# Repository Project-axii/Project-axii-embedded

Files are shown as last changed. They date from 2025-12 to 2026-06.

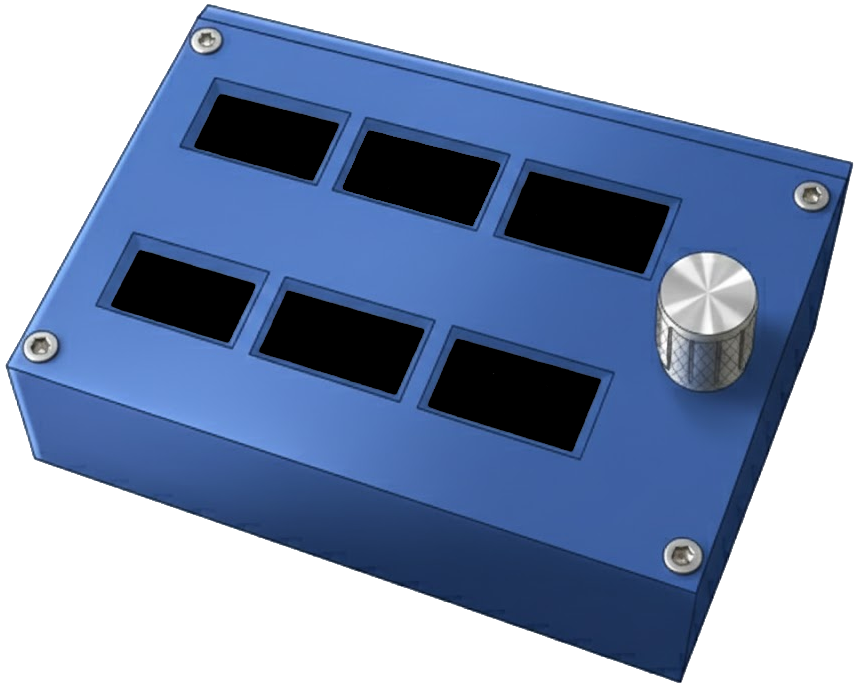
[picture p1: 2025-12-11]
Nexus/nexus.png

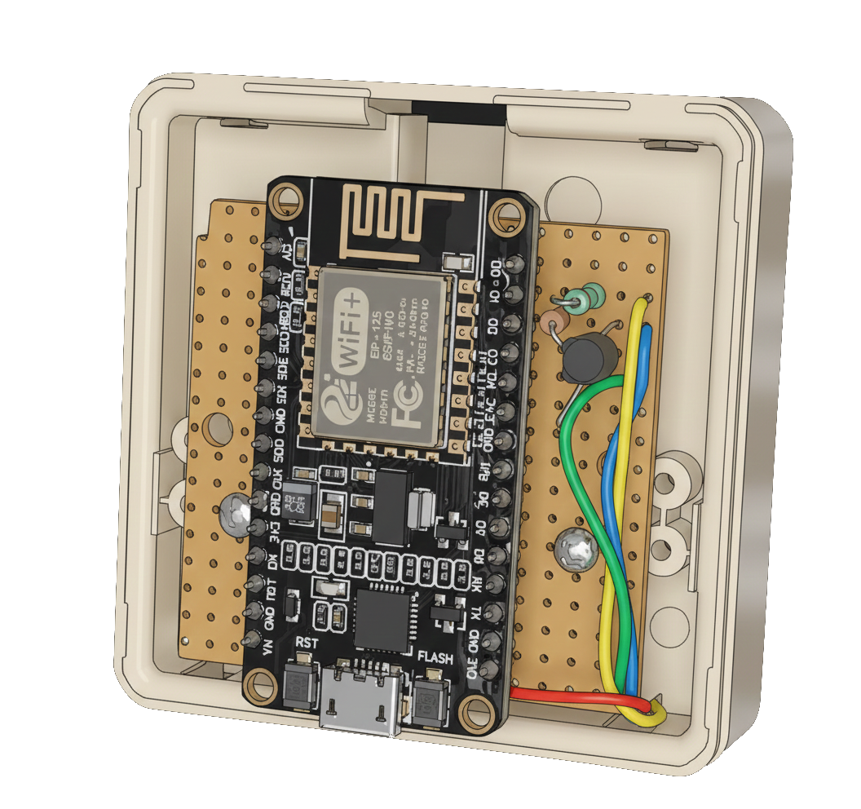
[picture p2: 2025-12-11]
Power Link/Power link.png

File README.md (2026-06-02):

<div align="center">

AXII Logo

# AXII — Embedded (Firmware IoT)

**Firmware dos dispositivos físicos do sistema AXII para automação de salas de aula, desenvolvido com ESP8266 e programado em C++ via Arduino IDE.**







</div>

---

## Sobre o Projeto

O **AXII Embedded** contém o firmware de três módulos físicos baseados em **ESP8266 (WeMos D1 Mini)** que integram o sistema AXII à infraestrutura real da sala de aula. Esses módulos se comunicam com a mesma API PHP compartilhada com o painel web e o app mobile, executando ações físicas com base no estado dos dispositivos registrados no banco de dados.

O sistema AXII completo é composto por:
- **Embedded** (este repositório) — módulos físicos IoT que atuam diretamente nos equipamentos
- **Web** — painel de controle via navegador
- **Mobile** — controle e monitoramento pelo celular
- **Desktop** — cliente instalado nos computadores das salas

---

## Módulos

### AX-LM — Controlador de Iluminação
Controla a **iluminação da sala** por meio de um relé conectado ao ESP8266. Consulta a API a cada 5 segundos e liga ou desliga a luz conforme o status do dispositivo.

### Power Link — Controle de Energia dos PCs
Simula o pressionamento do **botão físico de power** dos computadores. Detecta mudanças de estado na API e envia um pulso elétrico de 500ms ao botão de energia do PC.

### Nexus — Central de Controle Manual
Painel físico com **4 botões** que permite ao professor controlar todos os dispositivos da sala sem precisar do celular ou computador. Cada botão alterna o estado de um dispositivo na API.

---

## Como funciona

```
┌───────────────────────────────────────────┐
│              API AXII (PHP)               │
│         Banco de dados de dispositivos    │
└──────────────┬────────────────────────────┘
               │  HTTP (GET/POST)
    ┌──────────┼─────────────────────┐
    ↓           ↓                    ↓
┌─────────┐  ┌────────────┐   ┌──────────┐
│  AX-LM  │  │ Power Link │   │  Nexus   │
│ (Relé)  │  │ (Pulso D2) │   │(4 Botões)│
│ ID: 7   │  │  ID: 6     │   │IDs:4,5,6,7│
└─────────┘  └────────────┘   └──────────┘
 Iluminação   Liga/desliga PC   Controle manual
```

**Fluxo de controle:**
- **AX-LM e Power Link** — controladores automáticos: consultam a API periodicamente e executam ações físicas com base no status retornado.
- **Nexus** — controlador manual: o botão pressiona → atualiza o status na API → os outros módulos respondem automaticamente à mudança.

---

## Módulos em Detalhe

### AX-LM — Controlador de Iluminação

| Propriedade | Valor |
|---|---|
| Arquivo | `AX-LM/wemos_lamp.ino` |
| ID do Dispositivo | `7` |
| Pino GPIO | `D2` (relé) |
| AP de Configuração | `AX-LM_CONFIG` / senha: `12345678` |
| OTA Hostname | `AX-LM` |
| OTA Senha | `admin123` |
| Intervalo de Consulta | 5 segundos |

**Lógica de operação:**
- Consulta a API a cada 5 segundos com `GET {apiBaseUrl}?id=7`
- Se `ativo = true` e `status = "offline"` → **liga o relé** (iluminação acesa)
- Se `ativo = false` ou `status = "online"` → **desliga o relé** (iluminação apagada)
- Atualiza o campo `ultima_conexao` na API ao ligar o relé

**Arquivos de hardware:**
- `circuito.pdf` — diagrama do circuito elétrico

---

### Power Link — Controle de Energia dos PCs

| Propriedade | Valor |
|---|---|
| Arquivo | `Power Link/wemos_pc.ino` |
| ID do Dispositivo | `6` |
| Pino GPIO | `D2` (pulso no botão de power) |
| AP de Configuração | `AXII_POWERLINK` / senha: `12345678` |
| OTA Hostname | `AXII Power Link` |
| OTA Senha | `admin123` |
| Duração do Pulso | 500ms |
| Intervalo de Consulta | 5 segundos |

**Lógica de operação:**
- Consulta a API a cada 5 segundos com `GET {apiBaseUrl}?id=6`
- Armazena o estado inicial na primeira leitura
- Quando detecta uma **mudança de estado** (`online → offline` ou `offline → online`) → envia um pulso de 500ms no pino D2
- O pulso simula o pressionamento físico do botão de power do PC
- Atualiza `ultima_conexao` na API após cada acionamento

**Arquivos de hardware:**
- `circuito.png` — diagrama do circuito
- `Power link.png` — foto/referência visual do módulo

---

### Nexus — Central de Controle Manual

| Propriedade | Valor |
|---|---|
| Arquivo | `Nexus/wemos-nexus.ino` |
| Pinos GPIO | `D5`, `D6`, `D7`, `D8` (botões) |
| AP de Configuração | `NEXUS_CONFIG` / senha: `12345678` |
| OTA Hostname | `ESP8266-NEXUS` |
| OTA Senha | `admin` |
| Debounce | 200ms |

**Mapeamento de botões:**

| Botão | Pino | ID Dispositivo | Equipamento |
|---|---|---|---|
| Botão 1 | `D5` | 7 | PC / Lab |
| Botão 2 | `D6` | 6 | Ar-condicionado |
| Botão 3 | `D7` | 4 | Projetor |
| Botão 4 | `D8` | 5 | Iluminação |

**Lógica de operação:**
- Ao pressionar um botão, consulta o status atual do dispositivo na API
- Alterna o status: `online → offline` ou `offline → online`
- Envia o novo status via `POST` à API
- LED embutido pisca ao pressionar um botão
- **Reset manual:** segure o botão D5 por 3 segundos para apagar as credenciais WiFi salvas

**Arquivos de hardware:**
- `circuit.pdf` — diagrama do circuito elétrico
- `nexus.png` — foto/referência visual do módulo
- `model 3d/AXII Nexus.stl` — modelo 3D para impressão da carcaça
- `model 3d/AXII Nexus.glb` — modelo 3D em formato GLB (visualização)

---

## Funcionalidades Comuns

Todos os três módulos compartilham as seguintes funcionalidades:

| Funcionalidade | Descrição |
|---|---|
| **Portal de Configuração WiFi** | Ao ligar sem credenciais salvas, cria um ponto de acesso WiFi próprio. O usuário conecta e acessa `http://192.168.4.1` para configurar a rede via navegador |
| **Persistência em EEPROM** | As credenciais WiFi são salvas na memória interna do ESP8266 e sobrevivem a reinicializações |
| **Reconexão automática** | Se o WiFi cair, tenta reconectar automaticamente. Após 5 falhas consecutivas, entra novamente em modo de configuração |
| **OTA (Over-the-Air)** | Atualização de firmware via rede WiFi sem precisar conectar o cabo USB |
| **Monitor Serial** | Logs detalhados via porta serial a 115200 baud para depuração |
| **Limpeza de configuração** | Interface web com botão para apagar credenciais e retornar ao modo de configuração |

---

## Integração com a API

Todos os módulos se comunicam com a API via HTTP. A URL base deve ser configurada na constante `apiBaseUrl` em cada arquivo `.ino`.

### Endpoints utilizados

| Método | Chamada | Descrição |
|---|---|---|
| `GET` | `{apiBaseUrl}?id={idDispositivo}` | Consulta o status atual do dispositivo |
| `GET` | `{apiBaseUrl}?action=update&id={idDispositivo}` | Atualiza o campo `ultima_conexao` |
| `POST` | `{apiBaseUrl}` com body JSON | Alterna o status do dispositivo (Nexus) |

### Formatos de resposta suportados

Os módulos aceitam dois formatos de resposta da API:

```json
// Formato 1
{
  "success": true,
  "data": {
    "id": 7,
    "nome": "Iluminação Sala A",
    "status": "online",
    "ativo": true
  }
}

// Formato 2 (resposta direta)
{
  "id": 7,
  "nome": "Iluminação Sala A",
  "status": "online",
  "ativo": true
}
```

### Payload de atualização de status (Nexus)

```json
POST {apiBaseUrl}
Content-Type: application/json

{
  "id": 7,
  "status": "offline"
}
```

---

## Requisitos de Hardware

### Componentes comuns (todos os módulos)
- **Microcontrolador:** ESP8266 — WeMos D1 Mini (ou equivalente)
- **Alimentação:** 5V via USB
- **Rede WiFi:** 2,4 GHz (o ESP8266 não suporta 5 GHz)

### Componentes por módulo

| Módulo | Hardware adicional |
|---|---|
| **AX-LM** | 1× módulo relé (5V), fiação, luminária |
| **Power Link** | Fios de conexão ao botão de power do PC; optoacoplador ou relé recomendado para isolação elétrica |
| **Nexus** | 4× push buttons, LED embutido no ESP8266, carcaça impressa em 3D (opcional — arquivo STL incluso) |

---

## Bibliotecas Arduino Necessárias

| Biblioteca | Origem | Uso |
|---|---|---|
| `ESP8266WiFi` | ESP8266 Core | Conexão WiFi |
| `ESP8266WebServer` | ESP8266 Core | Portal de configuração captive |
| `ESP8266HTTPClient` | ESP8266 Core | Requisições HTTP à API |
| `ArduinoJson` | Benoit Blanchon (v6.x) | Parsing das respostas JSON da API |
| `ArduinoOTA` | ESP8266 Core | Atualização de firmware via rede |
| `EEPROM` | ESP8266 Core | Persistência das credenciais WiFi |

---

## Como Programar

### 1. Instalar o Arduino IDE

Baixe o [Arduino IDE](https://www.arduino.cc/en/software) (versão 1.8.x ou 2.x).

### 2. Adicionar suporte ao ESP8266

1. Abra o Arduino IDE → **Arquivo** → **Preferências**
2. Em "URLs adicionais para gerenciadores de placas", adicione:
   ```
   http://arduino.esp8266.com/stable/package_esp8266com_index.json
   ```
3. Vá em **Ferramentas** → **Placa** → **Gerenciador de Placas**
4. Pesquise `esp8266` e instale

### 3. Instalar bibliotecas

1. Vá em **Sketch** → **Incluir Biblioteca** → **Gerenciar Bibliotecas**
2. Pesquise e instale: **ArduinoJson** (versão 6.x, autor: Benoit Blanchon)
3. As demais bibliotecas vêm com o ESP8266 Core

### 4. Configurar o firmware

Abra o arquivo `.ino` do módulo desejado e configure:

```cpp
// URL da API (substitua pelo endereço real)
const char* apiBaseUrl = "http://seu-servidor.com/tcc-axii/Project-Axii-api/api/devices/list.php";

// ID do dispositivo no banco de dados (verifique na API)
const int idDispositivo = 7;
```

> As credenciais WiFi **não precisam** ser inseridas no código — elas são configuradas pelo portal web após a primeira inicialização.

### 5. Fazer upload

1. Conecte o ESP8266 via USB ao computador
2. Selecione a placa: **Ferramentas** → **Placa** → **ESP8266 Boards** → **WeMos D1 R1**
3. Selecione a porta COM correta em **Ferramentas** → **Porta**
4. Clique em **Upload** (→) e aguarde a compilação e gravação

---

## Configuração WiFi no Dispositivo

Após o upload, na primeira inicialização (ou após limpar as credenciais):

1. O módulo cria uma rede WiFi própria (ex: `AX-LM_CONFIG`)
2. Conecte seu celular ou computador a essa rede (senha: `12345678`)
3. Acesse `http://192.168.4.1` no navegador
4. Preencha o SSID e a senha da sua rede WiFi da escola
5. Clique em **Conectar à Rede** — o dispositivo reinicia e entra em operação normal

---

## Atualização OTA (Over-the-Air)

Após a configuração inicial, os módulos podem ser atualizados sem cabo USB:

1. Certifique-se de que o dispositivo está ligado e na mesma rede
2. No Arduino IDE, vá em **Ferramentas** → **Porta** e selecione o dispositivo na rede
3. Digite a senha OTA quando solicitado
4. Faça o upload normalmente

**Senhas e hostnames OTA:**

| Módulo | Hostname OTA | Senha OTA |
|---|---|---|
| AX-LM | `AX-LM` | `admin123` |
| Power Link | `AXII Power Link` | `admin123` |
| Nexus | `ESP8266-NEXUS` | `admin` |

---

## Estrutura do Repositório

```
Project-axii-embedded/
├── AX-LM/
│   ├── wemos_lamp.ino        # Firmware do controlador de iluminação
│   └── circuito.pdf          # Diagrama do circuito elétrico
│
├── Power Link/
│   ├── wemos_pc.ino          # Firmware do controlador de energia dos PCs
│   ├── circuito.png          # Diagrama do circuito
│   └── Power link.png        # Referência visual do módulo
│
├── Nexus/
│   ├── wemos-nexus.ino       # Firmware da central de controle manual
│   ├── circuit.pdf           # Diagrama do circuito elétrico
│   ├── nexus.png             # Foto/referência visual do módulo
│   └── model 3d/
│       ├── AXII Nexus.stl    # Modelo 3D para impressão da carcaça
│       ├── AXII Nexus.glb    # Modelo 3D para visualização
│       └── AXII Nexus.zip    # Arquivos do modelo compactados
│
└── LICENSE
```

---

## Depuração (Serial Monitor)

Conecte o cabo USB e abra o Monitor Serial do Arduino IDE em **115200 baud** para ver os logs em tempo real:

```
========================================
    AXII - Controle de AX-LM
   com Configuração WiFi Integrada
========================================

Credenciais encontradas:
SSID: MinhaRedeEscola
Conectando em: MinhaRedaEscola
...............
 WiFi conectado!
IP: 192.168.1.105
Sistema pronto para uso!

--- Consultando Dispositivo ---
URL: http://servidor.com/api/devices/list.php?id=7
Código HTTP: 200
Status: offline | Ativo: SIM
>>> RELÉ LIGADO - AX-LM ACESA <<<
```

---

## Avisos de Segurança

> **Atenção:** O módulo **AX-LM** pode estar conectado à rede elétrica (iluminação de 127V/220V). Sempre utilize um relé adequado com isolação elétrica e, se necessário, consulte um eletricista. Nunca manipule fiação elétrica com o circuito energizado.

> O módulo **Power Link** é conectado ao botão de power do PC. Recomenda-se o uso de um optoacoplador para isolar eletricamente o ESP8266 do computador.

> Altere as senhas OTA padrão (`admin123` / `admin`) antes de usar em ambiente de produção.

---

## 📄 Licença

Este projeto está licenciado sob a [Licença MIT](LICENSE).

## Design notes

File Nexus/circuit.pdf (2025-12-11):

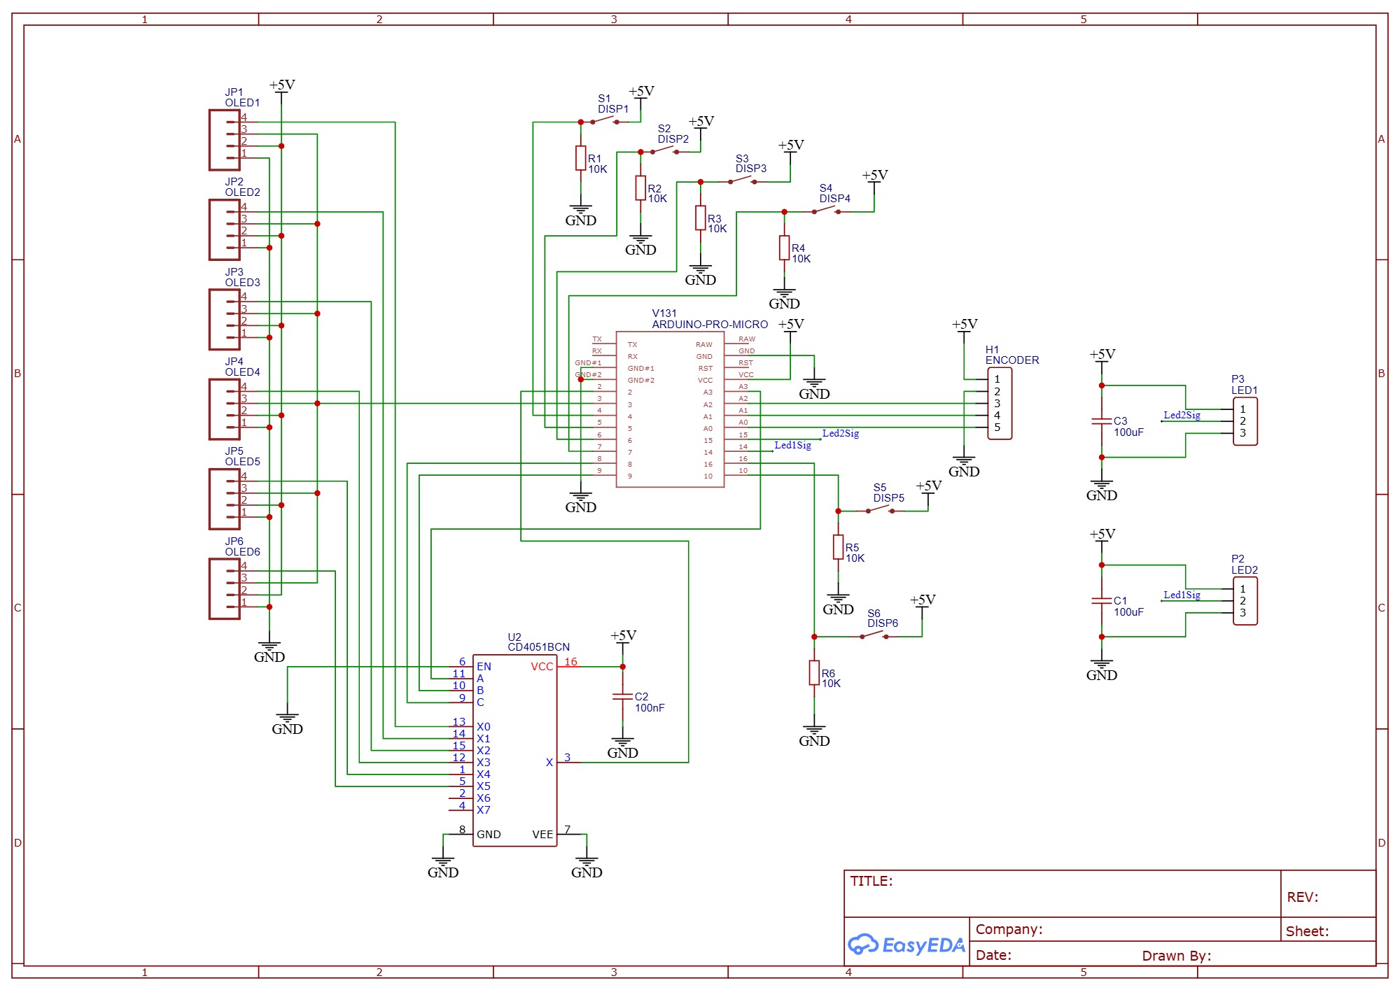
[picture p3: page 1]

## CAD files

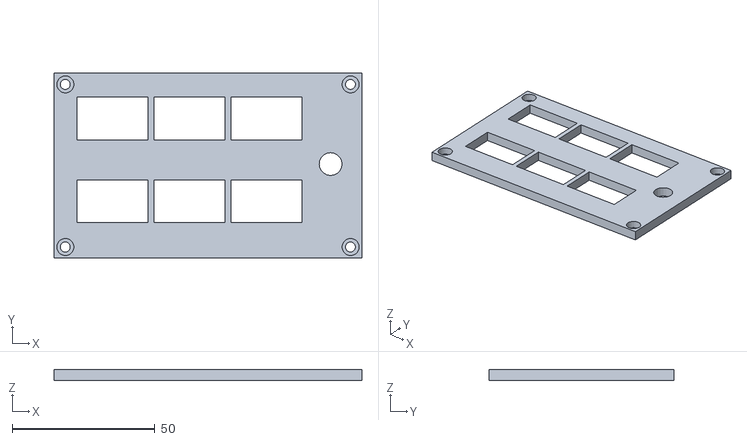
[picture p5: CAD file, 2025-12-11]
Nexus/model 3d/AXII Nexus.stl
108.0 x 65.0 x 4.00

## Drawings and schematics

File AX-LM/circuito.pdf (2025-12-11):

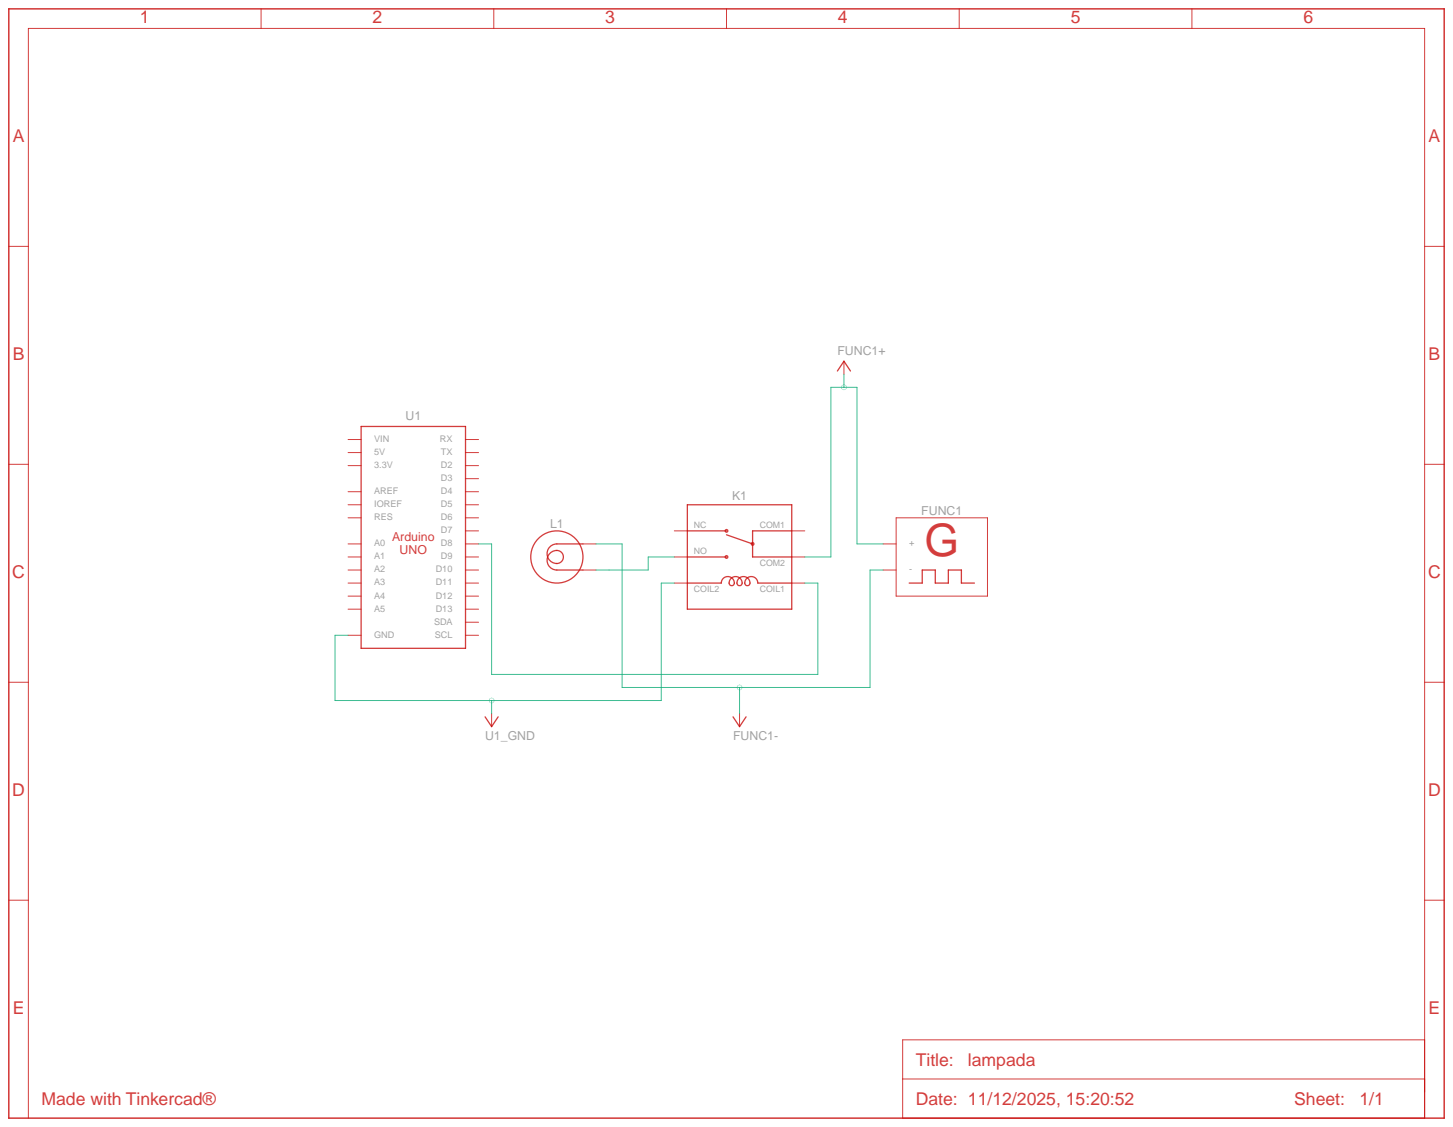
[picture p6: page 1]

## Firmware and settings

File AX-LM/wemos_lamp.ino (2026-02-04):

#include <ESP8266WiFi.h>
#include <ESP8266WebServer.h>
#include <ESP8266HTTPClient.h>
#include <ArduinoJson.h>
#include <ArduinoOTA.h>
#include <EEPROM.h>

// ==================== CONFIGURAÇÕES ====================
const char* apSSID = "AX-LM_CONFIG";        
const char* apPassword = "12345678";        
const char* apiBaseUrl = "LINK_API_DISPOSITIVOS";

const int idDispositivo = 7;

const int pinoRele = D2;

// ==================== VARIÁVEIS GLOBAIS ====================
ESP8266WebServer server(80);
String ssid = "";
String password = "";
bool modoConfiguracao = false;
int falhasConexao = 0;

unsigned long ultimaConsulta = 0;
const unsigned long intervaloConsulta = 5000; 
bool releAtivo = false;

const int LED_BUILTIN_PIN = LED_BUILTIN;

// ==================== FUNÇÕES DE EEPROM ====================
void salvarWiFi(String s, String p) {
  EEPROM.begin(512);
  
  for (int i = 0; i < 200; i++) {
    EEPROM.write(i, 0);
  }
  
  for (int i = 0; i < s.length() && i < 99; i++) {
    EEPROM.write(i, s[i]);
  }
  
  EEPROM.write(100, '|');
  
  for (int i = 0; i < p.length() && i < 99; i++) {
    EEPROM.write(101 + i, p[i]);
  }
  
  EEPROM.commit();
  EEPROM.end();
  
  Serial.println("=== Salvando na EEPROM ===");
  Serial.println("SSID: " + s);
  Serial.print("Senha: ");
  for(int i = 0; i < p.length(); i++) {
    Serial.print("*");
  }
  Serial.println("\n========================");
}

void lerWiFi() {
  EEPROM.begin(512);
  ssid = "";
  password = "";
  
  for (int i = 0; i < 100; i++) {
    char c = EEPROM.read(i);
    if (c == 0 || c == '|') break;
    ssid += c;
  }
  
  for (int i = 101; i < 200; i++) {
    char c = EEPROM.read(i);
    if (c == 0) break;
    password += c;
  }
  
  EEPROM.end();
  
  if (ssid.length() > 0) {
    Serial.println("Credenciais encontradas:");
    Serial.println("SSID: " + ssid);
    Serial.print("Senha: ");
    for(int i = 0; i < password.length(); i++) {
      Serial.print("*");
    }
    Serial.println();
  } else {
    Serial.println("Nenhuma credencial salva");
  }
}

void limparWiFi() {
  EEPROM.begin(512);
  for (int i = 0; i < 200; i++) {
    EEPROM.write(i, 0);
  }
  EEPROM.commit();
  EEPROM.end();
  Serial.println("Credenciais apagadas!");
}

// ==================== SERVIDOR WEB ====================
void handleRoot() {
  String page = R"rawliteral(
  <!DOCTYPE html>
  <html lang="pt-BR">
  <head>
    <meta charset="UTF-8">
    <meta name="viewport" content="width=device-width, initial-scale=1.0">
    <title>AX-LM - Configuração WiFi</title>
    <style>
      * { 
        margin: 0; 
        padding: 0; 
        box-sizing: border-box; 
      }
      
      body {
        font-family: -apple-system, BlinkMacSystemFont, 'Segoe UI', Arial, sans-serif;
        background: linear-gradient(135deg, #1e3c72 0%, #2a5298 50%, #7e22ce 100%);
        min-height: 100vh;
        display: flex;
        flex-direction: column;
        padding: 20px;
        color: #ffffff;
      }
      
      .header {
        display: flex;
        align-items: center;
        justify-content: space-between;
        padding: 20px 0;
        margin-bottom: 30px;
      }
      
      .logo {
        display: flex;
        align-items: center;
        gap: 10px;
      }
      
      .logo-icon {
        width: 40px;
        height: 40px;
        background: #ffc107;
        border-radius: 8px;
        display: flex;
        align-items: center;
        justify-content: center;
        font-weight: bold;
        font-size: 20px;
      }
      
      .logo-text {
        font-size: 28px;
        font-weight: bold;
        letter-spacing: 2px;
      }
      
      .subtitle {
        font-size: 14px;
        color: rgba(255, 255, 255, 0.7);
        font-weight: normal;
        letter-spacing: 1px;
      }
      
      .status-badge {
        background: rgba(255, 193, 7, 0.2);
        padding: 8px 16px;
        border-radius: 20px;
        font-size: 12px;
        backdrop-filter: blur(10px);
        border: 1px solid rgba(255, 193, 7, 0.3);
      }
      
      .container {
        max-width: 500px;
        width: 100%;
        margin: 0 auto;
      }
      
      .card {
        background: rgba(30, 41, 59, 0.7);
        border-radius: 16px;
        padding: 32px;
        backdrop-filter: blur(20px);
        border: 1px solid rgba(255, 255, 255, 0.1);
        box-shadow: 0 20px 60px rgba(0, 0, 0, 0.3);
        margin-bottom: 20px;
      }
      
      .card-title {
        font-size: 22px;
        font-weight: 600;
        margin-bottom: 24px;
        color: #ffffff;
      }
      
      .info-box {
        background: rgba(255, 193, 7, 0.15);
        border-left: 3px solid #ffc107;
        padding: 16px;
        border-radius: 8px;
        margin-bottom: 24px;
      }
      
      .info-box p {
        font-size: 13px;
        line-height: 1.6;
        color: rgba(255, 255, 255, 0.9);
        margin-bottom: 8px;
      }
      
      .info-box p:last-child {
        margin-bottom: 0;
      }
      
      .form-group {
        margin-bottom: 20px;
      }
      
      label {
        display: block;
        font-size: 14px;
        font-weight: 500;
        margin-bottom: 8px;
        color: rgba(255, 255, 255, 0.9);
      }
      
      input[type="text"], 
      input[type="password"] {
        width: 100%;
        padding: 14px;
        background: rgba(255, 255, 255, 0.1);
        border: 1px solid rgba(255, 255, 255, 0.2);
        border-radius: 8px;
        font-size: 15px;
        color: #ffffff;
        transition: all 0.3s;
      }
      
      input[type="text"]::placeholder,
      input[type="password"]::placeholder {
        color: rgba(255, 255, 255, 0.5);
      }
      
      input[type="text"]:focus, 
      input[type="password"]:focus {
        outline: none;
        background: rgba(255, 255, 255, 0.15);
        border-color: #ffc107;
        box-shadow: 0 0 0 3px rgba(255, 193, 7, 0.2);
      }
      
      .btn {
        width: 100%;
        padding: 14px;
        background: #ffc107;
        color: #1e3c72;
        border: none;
        border-radius: 8px;
        font-size: 15px;
        font-weight: 600;
        cursor: pointer;
        transition: all 0.3s;
        margin-top: 12px;
        box-shadow: 0 4px 12px rgba(255, 193, 7, 0.3);
      }
      
      .btn:hover {
        background: #ffb300;
        transform: translateY(-2px);
        box-shadow: 0 6px 20px rgba(255, 193, 7, 0.4);
      }
      
      .btn:active {
        transform: translateY(0);
      }
      
      .btn-reset {
        background: rgba(239, 68, 68, 0.8);
        color: white;
        box-shadow: 0 4px 12px rgba(239, 68, 68, 0.3);
      }
      
      .btn-reset:hover {
        background: rgba(220, 38, 38, 0.9);
        box-shadow: 0 6px 20px rgba(239, 68, 68, 0.4);
      }
      
      .footer {
        text-align: center;
        margin-top: 20px;
        font-size: 13px;
        color: rgba(255, 255, 255, 0.6);
      }
      
      .lamp-icon {
        display: inline-block;
        width: 20px;
        height: 20px;
        background: linear-gradient(135deg, #ffc107 0%, #ff9800 100%);
        border-radius: 50%;
        margin-right: 8px;
        vertical-align: middle;
        box-shadow: 0 0 10px rgba(255, 193, 7, 0.5);
      }
    </style>
  </head>
  <body>
    <div class="header">
      <div class="logo">
        <div class="logo-icon">A</div>
        <div>
          <div class="logo-text">AXII</div>
          <div class="subtitle">AX-LM</div>
        </div>
      </div>
      <div class="status-badge">Modo Configuração</div>
    </div>
    
    <div class="container">
      <div class="card">
        <h2 class="card-title">
          <span class="lamp-icon"></span>
          Configuração de Rede WiFi
        </h2>
        
        <div class="info-box">
          <p><strong>Instruções de Conexão:</strong></p>
          <p>1. Digite o nome da sua rede WiFi (SSID)</p>
          <p>2. Digite a senha da rede</p>
          <p>3. Clique em "Conectar à Rede"</p>
          <p>4. O dispositivo irá reiniciar e controlar a AX-LM automaticamente</p>
        </div>
        
        <form action="/save" method="GET">
          <div class="form-group">
            <label for="ssid">Nome da Rede (SSID)</label>
            <input type="text" id="ssid" name="ssid" placeholder="Digite o nome da sua rede" required>
          </div>
          
          <div class="form-group">
            <label for="pass">Senha da Rede</label>
            <input type="password" id="pass" name="pass" placeholder="Digite a senha">
          </div>
          
          <button type="submit" class="btn">Conectar à Rede</button>
        </form>
      </div>
      
      <div class="card">
        <form action="/reset" method="GET">
          <button type="submit" class="btn btn-reset">Limpar Configurações</button>
        </form>
      </div>
      
      <div class="footer">
        <p>Servidor: 192.168.4.1 | AXII Smart Lighting System</p>
      </div>
    </div>
  </body>
  </html>
  )rawliteral";
  
  server.send(200, "text/html", page);
}

void handleSave() {
  String newSSID = server.arg("ssid");
  String newPASS = server.arg("pass");
  
  if (newSSID.length() == 0) {
    server.send(400, "text/html", "<html><body><h2>Erro: SSID vazio!</h2><a href='/'>Voltar</a></body></html>");
    return;
  }
  
  salvarWiFi(newSSID, newPASS);
  
String page = R"rawliteral(
  <!DOCTYPE html>
  <html>
  <head>
    <meta charset="UTF-8">
    <style>
      body { 
        font-family: Arial; 
        text-align: center; 
        padding: 50px;
        background: linear-gradient(135deg, #1e3c72 0%, #2a5298 50%, #7e22ce 100%);
        color: white;
        min-height: 100vh;
        display: flex;
        align-items: center;
        justify-content: center;
      }
      .box {
        background: rgba(30, 41, 59, 0.9);
        color: #fff;
        padding: 40px;
        border-radius: 15px;
        display: inline-block;
        box-shadow: 0 10px 40px rgba(0,0,0,0.3);
        border: 1px solid rgba(34, 197, 94, 0.3);
      }
      .spinner {
        border: 4px solid rgba(255, 255, 255, 0.3);
        border-top: 4px solid #ffc107;
        border-radius: 50%;
        width: 50px;
        height: 50px;
        animation: spin 1s linear infinite;
        margin: 20px auto;
      }
      @keyframes spin {
        0% { transform: rotate(0deg); }
        100% { transform: rotate(360deg); }
      }
      h2 { margin-bottom: 10px; }
      p { color: rgba(255, 255, 255, 0.8); line-height: 1.6; }
    </style>
  </head>
  <body>
    <div class="box">
      <h2>Configuração Salva!</h2>
      <div class="spinner"></div>
      <p>Reiniciando o dispositivo...</p>
      <p>O AX-LM estará pronto para uso em instantes.</p>
    </div>
  </body>
  </html>
  )rawliteral";
  
  server.send(200, "text/html", page);
  delay(2000);
  ESP.restart();
}

void handleReset() {
  limparWiFi();
  
  String page = R"rawliteral(
  <!DOCTYPE html>
  <html>
  <head>
    <meta charset="UTF-8">
    <style>
      body { 
        font-family: Arial; 
        text-align: center; 
        padding: 50px;
        background: linear-gradient(135deg, #dc2626 0%, #ef4444 100%);
        color: white;
        min-height: 100vh;
        display: flex;
        align-items: center;
        justify-content: center;
      }
      .box {
        background: rgba(30, 41, 59, 0.9);
        color: #fff;
        padding: 40px;
        border-radius: 15px;
        display: inline-block;
        border: 1px solid rgba(255, 255, 255, 0.2);
      }
      h2 { margin-bottom: 10px; }
      p { color: rgba(255, 255, 255, 0.8); }
    </style>
  </head>
  <body>
    <div class="box">
      <h2>Configuração Apagada!</h2>
      <p>O dispositivo irá reiniciar em modo de configuração.</p>
    </div>
  </body>
  </html>
  )rawliteral";
  
  server.send(200, "text/html", page);
  delay(2000);
  ESP.restart();
}

// ==================== CONEXÃO WIFI ====================
bool connectWiFi() {
  Serial.print("Conectando em: ");
  Serial.println(ssid);
  
  WiFi.mode(WIFI_STA);
  WiFi.begin(ssid.c_str(), password.c_str());
  
  int attempts = 0;
  while (WiFi.status() != WL_CONNECTED && attempts < 30) {
    delay(500);
    Serial.print(".");
    attempts++;
    digitalWrite(LED_BUILTIN_PIN, !digitalRead(LED_BUILTIN_PIN));
  }
  
  if (WiFi.status() == WL_CONNECTED) {
    digitalWrite(LED_BUILTIN_PIN, HIGH);
    Serial.println("\n WiFi conectado!");
    Serial.print("IP: ");
    Serial.println(WiFi.localIP());
    return true;
  } else {
    Serial.println("\n Falha ao conectar WiFi!");
    return false;
  }
}

void iniciarModoConfiguracao() {
  modoConfiguracao = true;
  
  Serial.println("\n=== MODO CONFIGURAÇÃO ===");
  WiFi.mode(WIFI_AP);
  WiFi.softAP(apSSID, apPassword);
  
  Serial.println("Ponto de acesso criado!");
  Serial.print("Nome da rede: ");
  Serial.println(apSSID);
  Serial.print("Senha: ");
  Serial.println(apPassword);
  Serial.print("IP do servidor: ");
  Serial.println(WiFi.softAPIP());
  Serial.println("\nConecte-se à rede e acesse: http://192.168.4.1");
  Serial.println("========================\n");
  
  server.on("/", handleRoot);
  server.on("/save", handleSave);
  server.on("/reset", handleReset);
  server.begin();
  
  for(int i = 0; i < 5; i++) {
    digitalWrite(LED_BUILTIN_PIN, LOW);
    delay(100);
    digitalWrite(LED_BUILTIN_PIN, HIGH);
    delay(100);
  }
}

// ==================== CONTROLE DA AX-LM ====================
void consultarDispositivo() {
  if (WiFi.status() != WL_CONNECTED) {
    Serial.println("Sem conexão WiFi");
    return;
  }
  
  WiFiClient client;
  HTTPClient http;
  
  String url = String(apiBaseUrl) + "?id=" + String(idDispositivo);
  
  Serial.println("--- Consultando Dispositivo ---");
  Serial.print("URL: ");
  Serial.println(url);
  
  http.begin(client, url);
  http.addHeader("Content-Type", "application/json");
  http.setTimeout(5000);
  
  int httpResponseCode = http.GET();
  
  Serial.print("Código HTTP: ");
  Serial.println(httpResponseCode);
  
  if (httpResponseCode == 200) {
    String payload = http.getString();
    Serial.print("Resposta: ");
    Serial.println(payload);
    
    DynamicJsonDocument doc(1024);
    DeserializationError error = deserializeJson(doc, payload);
    
    if (!error) {
      bool success = false;
      String status = "";
      bool ativo = false;
      String nome = "";
      
      if (doc.containsKey("success")) {
        success = doc["success"];
        if (success && doc.containsKey("data")) {
          status = doc["data"]["status"].as<String>();
          ativo = doc["data"]["ativo"].as<bool>();
          nome = doc["data"]["nome"].as<String>();
        }
      }
      else if (doc.containsKey("status")) {
        success = true;
        status = doc["status"].as<String>();
        ativo = doc["ativo"].as<bool>();
        nome = doc["nome"].as<String>();
      }
      
      if (success) {
        Serial.print("Nome: ");
        Serial.println(nome);
        Serial.print("Status: ");
        Serial.println(status);
        Serial.print("Ativo: ");
        Serial.println(ativo ? "SIM" : "NAO");
        
        if (ativo && status == "offline") {
          if (!releAtivo) {
            digitalWrite(pinoRele, HIGH);
            releAtivo = true;
            Serial.println(">>> RELÉ LIGADO - AX-LM ACESA <<<");
            atualizarUltimaConexao();
          } else {
            Serial.println(">>> RELÉ JÁ ESTÁ LIGADO <<<");
          }
        } else {
          if (releAtivo) {
            digitalWrite(pinoRele, LOW);
            releAtivo = false;
            Serial.println(">>> RELÉ DESLIGADO - AX-LM APAGADA <<<");
          } else {
            Serial.println(">>> RELÉ JÁ ESTÁ DESLIGADO <<<");
          }
        }
      } else {
        Serial.println("Dispositivo não encontrado");
      }
    } else {
      Serial.print("Erro ao parsear JSON: ");
      Serial.println(error.c_str());
    }
  }
  else if (httpResponseCode == 404) {
    Serial.println("Dispositivo não encontrado (404)");
  }
  else {
    Serial.print("Erro no servidor: ");
    Serial.println(httpResponseCode);
  }
  
  http.end();
  Serial.println("-------------------------------\n");
}

void atualizarUltimaConexao() {
  WiFiClient client;
  HTTPClient http;
  
  String url = String(apiBaseUrl) + "?action=update&id=" + String(idDispositivo);
  
  http.begin(client, url);
  http.setTimeout(5000);
  int httpResponseCode = http.GET();
  
  if (httpResponseCode == 200) {
    Serial.println("Última conexão atualizada!");
  }
  
  http.end();
}

// ==================== SETUP ====================
void setup() {
  Serial.begin(115200);
  delay(100);
  
  Serial.println("\n\n========================================");
  Serial.println("    AXII - Controle de AX-LM");
  Serial.println("   com Configuração WiFi Integrada");
  Serial.println("========================================\n");
  
  pinMode(LED_BUILTIN_PIN, OUTPUT);
  digitalWrite(LED_BUILTIN_PIN, HIGH);
  
  pinMode(pinoRele, OUTPUT);
  digitalWrite(pinoRele, LOW);
  Serial.println("Relé configurado - Estado: DESLIGADO\n");
  
  lerWiFi();
  
  if (ssid.length() > 0) {
    bool conectado = false;
    for(int tentativa = 1; tentativa <= 3; tentativa++) {
      Serial.print("Tentativa ");
      Serial.print(tentativa);
      Serial.println(" de 3...");
      
      if (connectWiFi()) {
        conectado = true;
        break;
      }
      
      if (tentativa < 3) {
        Serial.println("Aguardando 2 segundos antes de tentar novamente...\n");
        delay(2000);
      }
    }
    
    if (conectado) {
      ArduinoOTA.setHostname("AX-LM");
      ArduinoOTA.setPassword("admin123");
      ArduinoOTA.setPort(8266);
      
      ArduinoOTA.onStart([]() {
        Serial.println("\n Iniciando atualização OTA...");
        digitalWrite(pinoRele, LOW);
        releAtivo = false;
      });
      
      ArduinoOTA.onEnd([]() {
        Serial.println("\n Atualização concluída!");
      });
      
      ArduinoOTA.onProgress([](unsigned int progress, unsigned int total) {
        Serial.printf("Progresso: %u%%\r", (progress / (total / 100)));
      });
      
      ArduinoOTA.onError([](ota_error_t error) {
        Serial.printf("Erro[%u]: ", error);
        if (error == OTA_AUTH_ERROR) Serial.println("Falha autenticação");
        else if (error == OTA_BEGIN_ERROR) Serial.println("Falha ao iniciar");
        else if (error == OTA_CONNECT_ERROR) Serial.println("Falha conexão");
        else if (error == OTA_RECEIVE_ERROR) Serial.println("Falha recebimento");
        else if (error == OTA_END_ERROR) Serial.println("Falha finalização");
      });
      
      ArduinoOTA.begin();
      
      Serial.println("\n=== OTA CONFIGURADO ===");
      Serial.println("Nome: AX-LM");
      Serial.println("Senha: admin123");
      Serial.print("IP para OTA: ");
      Serial.println(WiFi.localIP());
      Serial.println("=======================\n");
      
      Serial.println("Sistema pronto para uso!");
      Serial.println("Modo: OPERAÇÃO NORMAL\n");
      
      for(int i = 0; i < 3; i++) {
        digitalWrite(LED_BUILTIN_PIN, LOW);
        delay(200);
        digitalWrite(LED_BUILTIN_PIN, HIGH);
        delay(200);
      }
    } else {
      Serial.println("\n Não foi possível conectar após 3 tentativas!");
      Serial.println("Entrando em modo de configuração...\n");
      
      iniciarModoConfiguracao();
    }
  } else {
    iniciarModoConfiguracao();
  }
}

// ==================== LOOP ====================
void loop() {
  if (modoConfiguracao) {
    server.handleClient();
  } else {
    ArduinoOTA.handle();
    
    if (WiFi.status() != WL_CONNECTED) {
      falhasConexao++;
      Serial.print("WiFi desconectado! Tentando reconectar... (Falha ");
      Serial.print(falhasConexao);
      Serial.println("/5)");
      
      if(connectWiFi()) {
        falhasConexao = 0;
        Serial.println("Reconectado com sucesso!\n");
      } else {
        if(falhasConexao >= 5) {
          Serial.println("\n Muitas falhas de conexão!");
          Serial.println("Entrando em modo de configuração...");
          Serial.println("Verifique se a rede ainda existe ou se a senha mudou.\n");
          
          digitalWrite(pinoRele, LOW);
          releAtivo = false;
          
          iniciarModoConfiguracao();
          return;
        }
        delay(5000);
      }
      return;
    }
    
    if(falhasConexao > 0) {
      falhasConexao = 0;
    }
    
    if (millis() - ultimaConsulta >= intervaloConsulta) {
      ultimaConsulta = millis();
      consultarDispositivo();
    }
  }
  
  delay(100);
}

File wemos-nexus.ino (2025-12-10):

#include <ESP8266WiFi.h>
#include <ESP8266HTTPClient.h>
#include <ArduinoJson.h>
#include <ArduinoOTA.h>

const char* ssid = "Juliana2.4";
const char* password = "Juliana@2022";
const char* apiBaseUrl = "http://192.168.0.103/tcc-axii/lampada/change-state.php";

struct Botao {
  int pino;              
  int idDispositivo;     
  bool estadoAnterior;   
  unsigned long ultimoDebounce;
  bool botaoPressionado;
  String nome;           
};

Botao botoes[] = {
  {D5, 7, HIGH, 0, false, "Botao 1 - PC Lab"},
  {D6, 6, HIGH, 0, false, "Botao 2 - AC Lab"},
  {D7, 4, HIGH, 0, false, "Botao 3 - Projetor"},
  {D8, 5, HIGH, 0, false, "Botao 4 - Iluminacao"}
};

const int numBotoes = sizeof(botoes) / sizeof(botoes[0]);
const unsigned long debounceDelay = 200;
const int LED_BUILTIN_PIN = LED_BUILTIN;

void setup() {
  Serial.begin(115200);
  delay(100);
  
  pinMode(LED_BUILTIN_PIN, OUTPUT);
  digitalWrite(LED_BUILTIN_PIN, HIGH);
  
  Serial.println("\nSistema de Controle via Botoes");
  
  for (int i = 0; i < numBotoes; i++) {
    pinMode(botoes[i].pino, INPUT_PULLUP);
    delay(50);
  }
  
  connectWiFi();
  
  ArduinoOTA.setHostname("ESP8266-Controle");
  ArduinoOTA.setPassword("admin");
  
  ArduinoOTA.onStart([]() {
    Serial.println("\nIniciando OTA...");
  });
  
  ArduinoOTA.onEnd([]() {
    Serial.println("\nOTA concluido!");
  });
  
  ArduinoOTA.onProgress([](unsigned int progress, unsigned int total) {
    Serial.printf("Progresso: %u%%\r", (progress / (total / 100)));
  });
  
  ArduinoOTA.onError([](ota_error_t error) {
    Serial.printf("Erro[%u]: ", error);
    if (error == OTA_AUTH_ERROR) Serial.println("Falha autenticacao");
    else if (error == OTA_BEGIN_ERROR) Serial.println("Falha ao iniciar");
    else if (error == OTA_CONNECT_ERROR) Serial.println("Falha conexao");
    else if (error == OTA_RECEIVE_ERROR) Serial.println("Falha recebimento");
    else if (error == OTA_END_ERROR) Serial.println("Falha finalizacao");
  });
  
  ArduinoOTA.begin();
  
  Serial.println("Sistema pronto!\n");
  
  for(int i = 0; i < 3; i++) {
    digitalWrite(LED_BUILTIN_PIN, LOW);
    delay(100);
    digitalWrite(LED_BUILTIN_PIN, HIGH);
    delay(100);
  }
}

void loop() {
  ArduinoOTA.handle();
  
  if (WiFi.status() != WL_CONNECTED) {
    connectWiFi();
    delay(5000);
    return;
  }
  
  for (int i = 0; i < numBotoes; i++) {
    verificarBotao(i);
  }
  
  delay(10);
}

void connectWiFi() {
  Serial.print("Conectando WiFi");
  WiFi.mode(WIFI_STA);
  WiFi.begin(ssid, password);
  
  int attempts = 0;
  while (WiFi.status() != WL_CONNECTED && attempts < 30) {
    delay(500);
    Serial.print(".");
    attempts++;
    digitalWrite(LED_BUILTIN_PIN, !digitalRead(LED_BUILTIN_PIN));
  }
  
  if (WiFi.status() == WL_CONNECTED) {
    digitalWrite(LED_BUILTIN_PIN, HIGH);
    Serial.println("\nWiFi conectado!");
    Serial.print("IP: ");
    Serial.println(WiFi.localIP());
  } else {
    Serial.println("\nErro ao conectar WiFi!");
  }
}

void verificarBotao(int indice) {
  bool leituraAtual = digitalRead(botoes[indice].pino);
  
  if (leituraAtual != botoes[indice].estadoAnterior) {
    botoes[indice].ultimoDebounce = millis();
  }
  
  if ((millis() - botoes[indice].ultimoDebounce) > debounceDelay) {
    if (leituraAtual == LOW && !botoes[indice].botaoPressionado) {
      botoes[indice].botaoPressionado = true;
      digitalWrite(LED_BUILTIN_PIN, LOW);
      
      Serial.print("\nBotao pressionado: ");
      Serial.println(botoes[indice].nome);
      
      alternarEstadoDispositivo(botoes[indice].idDispositivo, botoes[indice].nome);
      digitalWrite(LED_BUILTIN_PIN, HIGH);
    }
    
    if (leituraAtual == HIGH && botoes[indice].botaoPressionado) {
      botoes[indice].botaoPressionado = false;
    }
  }
  
  botoes[indice].estadoAnterior = leituraAtual;
}

void alternarEstadoDispositivo(int idDispositivo, String nomeBotao) {
  if (WiFi.status() != WL_CONNECTED) {
    Serial.println("Erro: Sem conexao WiFi");
    return;
  }
  
  WiFiClient client;
  HTTPClient http;
  
  String urlConsulta = String(apiBaseUrl) + "?id=" + String(idDispositivo);
  http.begin(client, urlConsulta);
  http.setTimeout(5000);
  
  int httpCode = http.GET();
  
  if (httpCode != 200) {
    Serial.println("Erro ao consultar dispositivo");
    http.end();
    return;
  }
  
  String payload = http.getString();
  http.end();
  
  DynamicJsonDocument doc(1024);
  DeserializationError error = deserializeJson(doc, payload);
  
  if (error) {
    Serial.println("Erro ao parsear resposta");
    return;
  }
  
  String statusAtual = "";
  bool ativo = false;
  
  if (doc.containsKey("success") && doc["success"]) {
    statusAtual = doc["data"]["status"].as<String>();
    ativo = doc["data"]["ativo"].as<bool>();
  } else if (doc.containsKey("status")) {
    statusAtual = doc["status"].as<String>();
    ativo = doc["ativo"].as<bool>();
  } else {
    Serial.println("Formato de resposta inesperado");
    return;
  }
  
  if (!ativo) {
    Serial.println("Dispositivo desativado");
    return;
  }
  
  String novoStatus = (statusAtual == "online") ? "offline" : "online";
  
  DynamicJsonDocument docUpdate(256);
  docUpdate["id"] = idDispositivo;
  docUpdate["status"] = novoStatus;
  
  String jsonData;
  serializeJson(docUpdate, jsonData);
  
  HTTPClient httpUpdate;
  httpUpdate.begin(client, apiBaseUrl);
  httpUpdate.addHeader("Content-Type", "application/json");
  httpUpdate.setTimeout(5000);
  
  int httpPostCode = httpUpdate.POST(jsonData);
  
  if (httpPostCode == 200) {
    Serial.print("Sucesso! Dispositivo ID ");
    Serial.print(idDispositivo);
    Serial.print(" alterado para: ");
    Serial.println(novoStatus);
  } else {
    Serial.print("Erro ao atualizar. Codigo: ");
    Serial.println(httpPostCode);
  }
  
  httpUpdate.end();
}

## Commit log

2025-11-09 Add initial implementation of WiFi-controlled lamp and PC power system
2025-12-10 Add OTA functionality to WiFi-controlled lamp and PC power systems
2025-12-10 Implement WiFi-controlled button system with OTA updates and device state management
2025-12-11 Add documentation about the boards
    [AXII Nexus.stl]
2025-12-12 Add system architecture section and clarify device ID usage in README
